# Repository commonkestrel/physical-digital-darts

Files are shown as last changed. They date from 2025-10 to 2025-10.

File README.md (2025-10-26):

# Physical Digital Darts
## 💡 Inspiration

As a team who values accessible and immersive gaming experiences, we wanted to create a hack that embodied both of these ideas across software, hardware, and design. Taking inspiration from the Nintendo Wii and Switch consoles, we choose to create a Physical Digital Dart which allows the user to perform throwing motions as they would in real life, captures that motion with an accelerometer, and simulates the result on a digital dartboard.

---

## 🎯 What It Does

After the MPU6050 accelerometer reads its current angles, those angles are filtered for noise on the Arduino Nano which then transmits the button state, roll, pitch, and yaw of the Physical Digital Dart via serial monitor to our Python dartboard simulator which launches a dart in the correct direction on the button’s release at the angle given by the MPU6050.

To account for drift, a double tap of the button re-calibrates the dart’s orientation to a standardized orientation.

---

## 🛠️ How We Built It

To optimize space and keep the dart as small as possible, we utilized small gauge wires for connections and assembled them to minimize wire overlap. The dart-like 3D printed casing contains an Arduino nano which is connected to a MPU6050 accelerometer via perfboard  Along the side of the Physical Digital Dart is one button to keep track of the start (when pressed) and end of the throw (when released).

---

## 🧱 Challenges We Ran Into

The accelerometer we were provided is an MPU6050 accelerometer and gyroscope. This type of small MEMS sensor is great for finding orientation, but velocity and position are far out of reach for the level of inaccuracy and drift found in the sensor. In order to fix this, we developed a specialized filtering algorithm for our application that was able to combat these issues and keep the drift in check. 

Additionally, as we sought to use the 3D printers on the first day of the hackathon, we found that 3/4 were malfunctioning. In order to print our design and let others print theirs we worked through the night to fix the Prusa I3 Mark 2, the Ender 3, and the Ender 3 V2 SE, ultimately getting all 3 printers into a functioning state.

---

## 🏆 Accomplishments That We're Proud Of

1. Combining software, hardware, AND 3D design into a working product with very limited time 
2. Creating a product which can be adjusted in shape to meet the needs of its users
3. Creating a product which combines the physical and digital worlds, redefining what it means to “play a game."

---

## 📚 What We Learned

For our future hackathons, we noted that it would be best to bring as much personal hardware as needed, considering that there may not be a sufficient amount of hardware available to borrow from the venue. 

---

## 🚀 What's Next for Digital Physical Darts (Wii Darts)

### 2D → 3D
Since our current version is 2D, we would like to implement a 3D version with better visuals and more character. Some additional features include:
- Player-versus-player gameplay
- A Wii Sports-like aesthetics

### Fix Accelerometer Drift
Originally, our team wanted to track the position of the dart at all times but found that the drift of the MPU6050 made the double integration necessary to find that position highly accurate. A more precise accelerometer combined with a more intense filtering algorithm such as a Kalman filter would yield better results.

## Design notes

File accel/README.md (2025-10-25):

accel
=====

Rust project for the _Arduino Nano_.

## Build Instructions
1. Install prerequisites as described in the [`avr-hal` README] (`avr-gcc`, `avr-libc`, `avrdude`, [`ravedude`]).

2. Run `cargo build` to build the firmware.

3. Run `cargo run` to flash the firmware to a connected board.  If `ravedude`
   fails to detect your board, check its documentation at
   <https://crates.io/crates/ravedude>.

4. `ravedude` will open a console session after flashing where you can interact
   with the UART console of your board.

[`avr-hal` README]: https://github.com/Rahix/avr-hal#readme
[`ravedude`]: https://crates.io/crates/ravedude

## License
Licensed under either of

 - Apache License, Version 2.0
   ([LICENSE-APACHE](LICENSE-APACHE) or <http://www.apache.org/licenses/LICENSE-2.0>)
 - MIT license
   ([LICENSE-MIT](LICENSE-MIT) or <http://opensource.org/licenses/MIT>)

at your option.

## Contribution
Unless you explicitly state otherwise, any contribution intentionally submitted
for inclusion in the work by you, as defined in the Apache-2.0 license, shall
be dual licensed as above, without any additional terms or conditions.

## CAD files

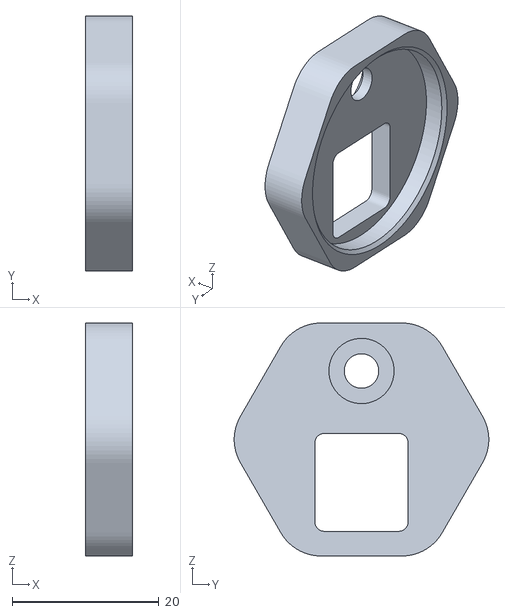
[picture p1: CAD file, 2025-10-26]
cad files/DartLid.stl
6.35 x 34.7 x 31.8

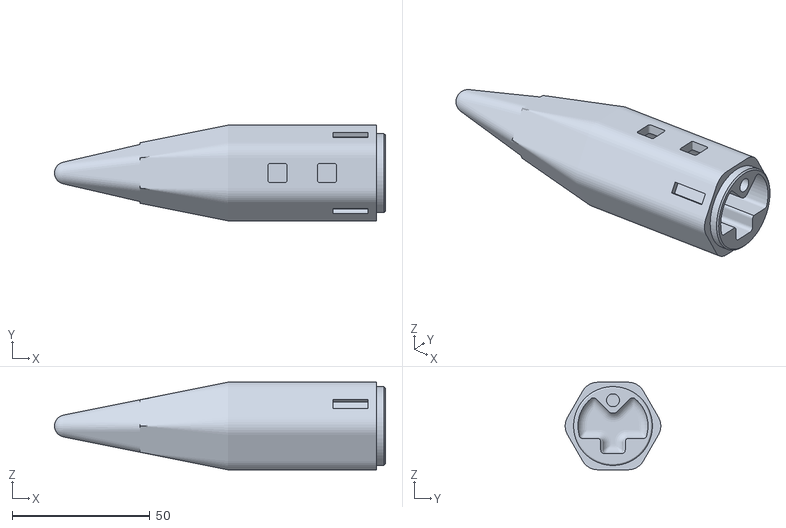
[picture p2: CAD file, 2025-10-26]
cad files/DartBody.stl
120.0 x 34.7 x 31.8

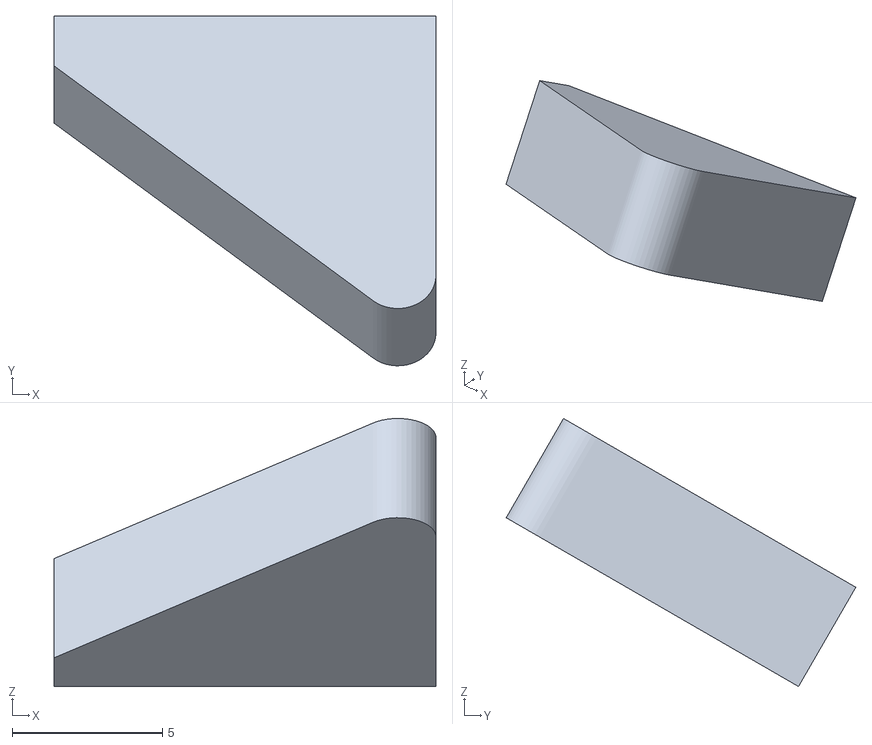
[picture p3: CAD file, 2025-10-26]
cad files/Fin (x3).stl
12.7 x 11.6 x 8.91

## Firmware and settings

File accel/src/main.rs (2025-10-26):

#![no_std]
#![no_main]
#![feature(abi_avr_interrupt)]

mod mpu6050;
mod rolling_buffer;
mod f32_ufmt;

use core::cell;

use micromath::F32Ext;
use panic_halt as _;
use arduino_hal::{delay_ms, i2c::I2c, prelude::*};

use crate::{f32_ufmt::ThreeFmt, mpu6050::Mpu6050, rolling_buffer::Collection};

const IMU_ADDR: u8 = 0x68;
const ALPHA: f32 = 0.85;

#[arduino_hal::entry]
fn main() -> ! {
    let dp = arduino_hal::Peripherals::take().unwrap();
    let pins = arduino_hal::pins!(dp);
    let mut serial = arduino_hal::default_serial!(dp, pins, 115200);

    millis_init(dp.TC0);

    // Enable interrupts globally
    unsafe { avr_device::interrupt::enable() };

    let button = pins.d3.into_pull_up_input();
    let i2c = I2c::new(
        dp.TWI,
        pins.a4.into_pull_up_input(),
        pins.a5.into_pull_up_input(),
        400000,
    );

    let mut imu = match Mpu6050::new(i2c, IMU_ADDR) {
        Ok(imu) => imu,
        Err(err) => {
            ufmt::uwriteln!(&mut serial, "{:?}", err).unwrap_infallible();
            panic!();
        }
    };

    ufmt::uwriteln!(&mut serial, "Connected!").unwrap_infallible();

    let init = imu.update().unwrap();
    let mut roll = (-init.accel_x).atan2((init.accel_y*init.accel_y + init.accel_z*init.accel_z).sqrt()).to_degrees();
    let mut pitch = init.accel_y.atan2(init.accel_z).to_degrees();
    let mut yaw = 0.;

    let mut vx = 0.;
    let mut prev_time = millis();
    let mut ax_gain = 0.;
    let mut gz_gain = 0.;
    let mut rolling: Collection<10> = Collection::new();
    let mut rolling_yaw: Collection<5> = Collection::new();
    let mut last_button = 0;

    let mut prev = button.is_low();
    loop {
        if let Ok(data) = imu.update() {
            let new = button.is_low();
            let event = match (prev, new) {
                (false, false) => 0,
                (true, true) => 1,
                (false, true) => 2,
                (true, false) => {
                    prev_time = millis();
                    if prev_time - last_button < 500 {
                        ax_gain = data.accel_x;
                        rolling.clear();
                        gz_gain = data.gyro_z;
                        rolling_yaw.clear();
                        roll = (-init.accel_x).atan2((init.accel_y*init.accel_y + init.accel_z*init.accel_z).sqrt()).to_degrees();
                        pitch = init.accel_y.atan2(init.accel_z).to_degrees();
                        yaw = 0.;
                        vx = 0.;
                        continue;
                    }
                    last_button = prev_time;
                    3
                },
            };
            prev = new;

            let time = millis();
            let dt = (time - prev_time) as f32 / 1000.0;

            if rolling_yaw.full() && (rolling_yaw.avg() - data.gyro_z).abs() < 0.25 {
                rolling_yaw.clear();
                gz_gain = data.gyro_z;
            } else {
                rolling_yaw.push(data.gyro_z);
            }

            roll += data.gyro_x * dt;
            pitch += data.gyro_y * dt;
            yaw += (data.gyro_z - gz_gain) * dt;
            
            // complimentary filter on our orientation :)
            let new_pitch = data.accel_y.atan2(data.accel_z).to_degrees();
            let new_roll = (-data.accel_x).atan2((data.accel_y*data.accel_y + data.accel_z*data.accel_z).sqrt()).to_degrees();

            if roll.signum() != new_pitch.signum() {
                pitch = new_pitch;
            }

            roll = ALPHA * roll + (1. - ALPHA) * new_roll;
            pitch = ALPHA * pitch + (1. - ALPHA) * new_pitch;

            if rolling.full() && (rolling.avg() - data.accel_x).abs() < 0.25 {
                rolling.clear();
                ax_gain = data.accel_x;
            } else {
                rolling.push(data.accel_x);
            }

            vx += deadband(data.accel_x - ax_gain, 1.) * dt;
            vx *= 0.5;

            prev_time = time;

            let fmtx = ThreeFmt(roll);
            let fmty = ThreeFmt(fix_pitch(pitch));
            let fmtz = ThreeFmt(yaw);
            let gx = ThreeFmt(vx.abs());
            ufmt::uwriteln!(&mut serial, "{} {} {} {} {}", event, fmtx, fmty, fmtz, gx).unwrap_infallible();

            delay_ms(50);
        }
    }
}

#[inline]
fn deadband(input: f32, band: f32) -> f32 {
    if input.abs() < band { 0. } else { input }
}

#[inline]
fn fix_pitch(pitch: f32) -> f32 {
    if pitch < 0. {
        return -90. - pitch;
    } else {
        return 270. - pitch;
    }
}

// Possible Values:
//
// ╔═══════════╦══════════════╦═══════════════════╗
// ║ PRESCALER ║ TIMER_COUNTS ║ Overflow Interval ║
// ╠═══════════╬══════════════╬═══════════════════╣
// ║        64 ║          250 ║              1 ms ║
// ║       256 ║          125 ║              2 ms ║
// ║       256 ║          250 ║              4 ms ║
// ║      1024 ║          125 ║              8 ms ║
// ║      1024 ║          250 ║             16 ms ║
// ╚═══════════╩══════════════╩═══════════════════╝
const PRESCALER: u32 = 1024;
const TIMER_COUNTS: u32 = 125;

const MILLIS_INCREMENT: u32 = PRESCALER * TIMER_COUNTS / 16000;

static MILLIS_COUNTER: avr_device::interrupt::Mutex<cell::Cell<u32>> =
    avr_device::interrupt::Mutex::new(cell::Cell::new(0));

fn millis_init(tc0: arduino_hal::pac::TC0) {
    // Configure the timer for the above interval (in CTC mode)
    // and enable its interrupt.
    tc0.tccr0a.write(|w| w.wgm0().ctc());
    tc0.ocr0a.write(|w| w.bits(TIMER_COUNTS as u8));
    tc0.tccr0b.write(|w| match PRESCALER {
        8 => w.cs0().prescale_8(),
        64 => w.cs0().prescale_64(),
        256 => w.cs0().prescale_256(),
        1024 => w.cs0().prescale_1024(),
        _ => panic!(),
    });
    tc0.timsk0.write(|w| w.ocie0a().set_bit());

    // Reset the global millisecond counter
    avr_device::interrupt::free(|cs| {
        MILLIS_COUNTER.borrow(cs).set(0);
    });
}

#[avr_device::interrupt(atmega328p)]
fn TIMER0_COMPA() {
    avr_device::interrupt::free(|cs| {
        let counter_cell = MILLIS_COUNTER.borrow(cs);
        let counter = counter_cell.get();
        counter_cell.set(counter + MILLIS_INCREMENT);
    })
}

fn millis() -> u32 {
    avr_device::interrupt::free(|cs| MILLIS_COUNTER.borrow(cs).get())
}

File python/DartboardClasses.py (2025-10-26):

import math
import pygame

class Dart:
    RADIUS = 40
    MIN_RADIUS = 10
    COLOR = (100,100,255)
    LIFETIME = 100
    TOLERANCE = 10
    all_darts = []
    def __init__(self, x, y, z, exit_velocity, screen, dartboard):
        Dart.all_darts.append(self)
        self.dartboard = dartboard
        self.should_decay = False
        self.on_dartboard = False
        self.velocity = exit_velocity
        self.velocity[1] = -self.velocity[1]
        self.lifetime = Dart.LIFETIME
        self.screen = screen
        self.starting_distance_from_dartboard = z #CURRENTLY DOESN'T ACTUALLY REPRESENT DISTANCE FROM DARTBOARD ON LAUNCH
        self.position = [x, y, z]

    def draw_self(self):
        if self.has_reached_dartboard_depth() and self.on_dartboard:
            self.should_decay = True

        if self.should_decay and self.lifetime > 0:
            self.lifetime -= 1

        if (self.should_decay and self.lifetime <= 0) or self.position[1] > self.screen.get_height()*2:
            Dart.all_darts.remove(self)
        
        percent_of_distance_traveled = (self.position[2]-self.starting_distance_from_dartboard)/(self.dartboard.position[2]-self.starting_distance_from_dartboard)
        pygame.draw.circle(self.screen, self.COLOR, self.position[:2], self.MIN_RADIUS+self.RADIUS*(1-percent_of_distance_traveled))

    def has_reached_dartboard_depth(self):
        at_or_past_dartboard = self.position[2] >= self.dartboard.position[2] and self.position[2] <= self.dartboard.position[2] + self.TOLERANCE
        return at_or_past_dartboard
       
    def __repr__(self):
        return "Dart Coordinates: " + str(self.position)
    
    @staticmethod
    def draw_all(screen):
        for dart in Dart.all_darts:
            dart.draw_self()

class Polar_Rectangle:
    HIT_COLOR = (0,0,255)
    def __init__(self, radius1, radius2, theta1, theta2, color, dartboard, screen):
        self.screen = screen
        self.dartboard = dartboard
        self.non_hit_color = color
        self.color = self.non_hit_color
        self.xy_corners = []
        self.xy_corners.append((radius1*math.cos(theta1), radius1*math.sin(theta1)))
        self.xy_corners.append((radius1*math.cos(theta2), radius1*math.sin(theta2)))
        self.xy_corners.append((radius2*math.cos(theta2), radius2*math.sin(theta2)))
        self.xy_corners.append((radius2*math.cos(theta1), radius2*math.sin(theta1)))
        self.xy_corners = Dartboard.cartesian_coordinates_to_pygame_coordinates(self.xy_corners, screen)

    def draw_self(self):
        pygame.draw.polygon(self.screen, self.color, self.xy_corners, 0)

    def check_for_collision(self, darts):
        has_collided = False
        for dart in darts:
            has_collided = self.point_in_polygon(dart.position, self.xy_corners)
            if has_collided:
                if dart.position[2] < self.dartboard.position[2]:
                    self.when_projected_collide()
                if dart.has_reached_dartboard_depth():
                    self.when_collide(dart)
                return True #Collided only in x-y projection
        self.color = self.non_hit_color
        return False
    
    def when_collide(self, dart):
        dart.on_dartboard = True
        #print(f'Collided with: {dart}')

    def when_projected_collide(self):
        self.color = self.HIT_COLOR
    
    def point_in_polygon(self, point, polygon):
        num_vertices = len(polygon)
        x, y = point[0], point[1]
        inside = False

        # Store the first point in the polygon and initialize the second point
        p1 = polygon[0]

        # Loop through each edge in the polygon
        for i in range(1, num_vertices + 1):
            # Get the next point in the polygon
            p2 = polygon[i % num_vertices]

            # Check if the point is above the minimum y coordinate of the edge
            if y > min(p1[1], p2[1]):
                # Check if the point is below the maximum y coordinate of the edge
                if y <= max(p1[1], p2[1]):
                    # Check if the point is to the left of the maximum x coordinate of the edge
                    if x <= max(p1[0], p2[0]):
                        # Calculate the x-intersection of the line connecting the point to the edge
                        x_intersection = (y - p1[1]) * (p2[0] - p1[0]) / (p2[1] - p1[1]) + p1[0]

                        # Check if the point is on the same line as the edge or to the left of the x-intersection
                        if p1[0] == p2[0] or x <= x_intersection:
                            # Flip the inside flag
                            inside = not inside

            # Store the current point as the first point for the next iteration
            p1 = p2

        # Return the value of the inside flag
        return inside


    def __repr__(self):
        return "Polar Rectangle Corners: " + str(self.xy_corners)
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

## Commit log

2025-10-25 arduino accel progress
2025-10-25 hopefully get calibration working
2025-10-25 Dart board layout has been acheived
2025-10-26 filtered :)
2025-10-26 was trying to center the board but gave up
2025-10-26 fix x velocity!
2025-10-26 WE ARE NOW OPEN SOURCE
    [DartBody.stl, DartLid.stl, Fin (x3).stl]
